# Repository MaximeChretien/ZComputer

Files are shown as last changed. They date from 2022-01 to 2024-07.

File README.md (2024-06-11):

# ZComputer

This projects aims to build a computer based on a Z80 CPU from scratch.

## Introduction

The computer is designed as a set of boards, each having a specific function.

The current planned boards are:
- Main (CPU, RAM, ROM, ...)
- Basic I/O
- Interrupt (Interrupt vector decoding and prioritizing)
- UART
- Counter/Timer
- ADC and DAC
- Storage

Those boards will then connect on the base board through a unified connector.  
The base board also includes the power input and the reset button as well as a power LED.

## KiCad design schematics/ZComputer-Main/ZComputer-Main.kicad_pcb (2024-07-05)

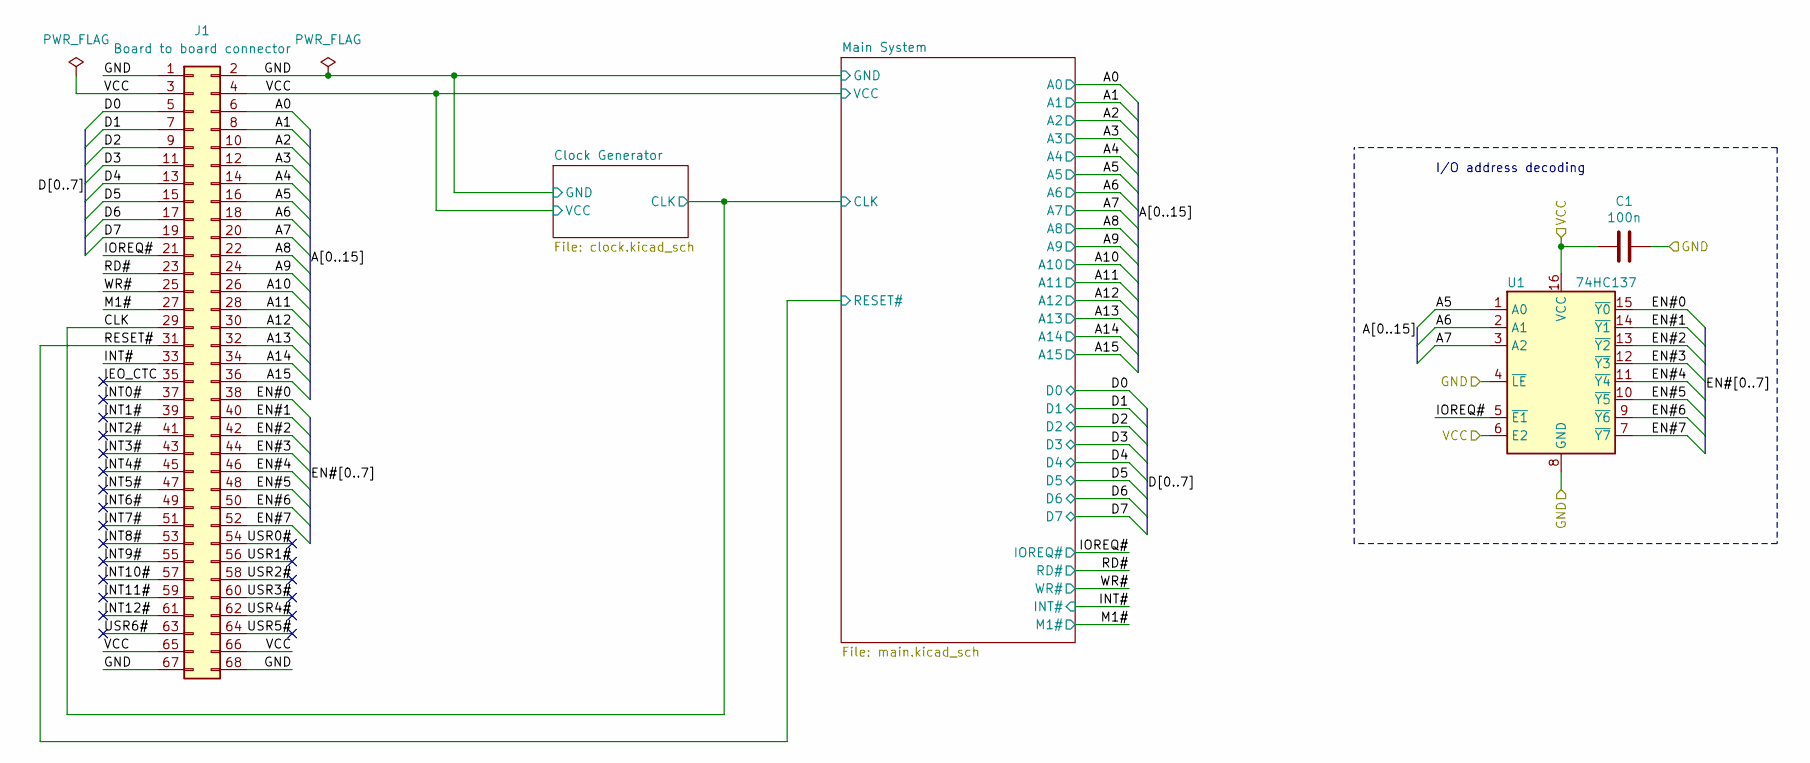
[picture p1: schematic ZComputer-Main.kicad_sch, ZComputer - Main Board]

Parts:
C1: 100n; C_Disc_D4.3mm_W1.9mm_P5.00mm
J1: Board to board connector; PinSocket_2x34_P2.54mm_Horizontal
U1: 74HC137; DIP-16_W7.62mm_Socket_LongPads

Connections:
/A0: J1.6; also elsewhere on the board
/A1: J1.8; also elsewhere on the board
/A2: J1.10; also elsewhere on the board
/A3: J1.12; also elsewhere on the board
/A4: J1.14; also elsewhere on the board
/A5: J1.16, U1.1 (A0); also elsewhere on the board
/A6: J1.18, U1.2 (A1); also elsewhere on the board
/A7: J1.20, U1.3 (A2); also elsewhere on the board
/A8: J1.22; also elsewhere on the board
/A9: J1.24; also elsewhere on the board
/A10: J1.26; also elsewhere on the board
/A11: J1.28; also elsewhere on the board
/A12: J1.30; also elsewhere on the board
/A13: J1.32; also elsewhere on the board
/A14: J1.34; also elsewhere on the board
/A15: J1.36; also elsewhere on the board
/CLK: J1.29; also elsewhere on the board
/D0: J1.5; also elsewhere on the board
/D1: J1.7; also elsewhere on the board
/D2: J1.9; also elsewhere on the board
/D3: J1.11; also elsewhere on the board
/D4: J1.13; also elsewhere on the board
/D5: J1.15; also elsewhere on the board
/D6: J1.17; also elsewhere on the board
/D7: J1.19; also elsewhere on the board
/EN#0: J1.38, U1.15 (~Y0)
/EN#1: J1.40, U1.14 (~Y1)
/EN#2: J1.42, U1.13 (~Y2)
/EN#3: J1.44, U1.12 (~Y3)
/EN#4: J1.46, U1.11 (~Y4)
/EN#5: J1.48, U1.10 (~Y5)
/EN#6: J1.50, U1.9 (~Y6)
/EN#7: J1.52, U1.7 (~Y7)
/GND: C1.1, J1.1, J1.2, J1.67, J1.68, U1.4 (~LE), U1.8 (GND); also elsewhere on the board
/IEO_CTC: J1.35
/INT0#: J1.37
/INT1#: J1.39
/INT2#: J1.41
/INT3#: J1.43
/INT4#: J1.45
/INT5#: J1.47
/INT6#: J1.49
/INT7#: J1.51
/INT8#: J1.53
/INT9#: J1.55
/INT10#: J1.57
/INT11#: J1.59
/INT12#: J1.61
/INT#: J1.33; also elsewhere on the board
/IOREQ#: J1.21, U1.5 (~E1); also elsewhere on the board
/M1#: J1.27; also elsewhere on the board
/RD#: J1.23; also elsewhere on the board
/RESET#: J1.31; also elsewhere on the board
/USR0#: J1.54
/USR1#: J1.56
/USR2#: J1.58
/USR3#: J1.60
/USR4#: J1.62
/USR5#: J1.64
/USR6#: J1.63
/VCC: C1.2, J1.3, J1.4, J1.65, J1.66, U1.6 (E2), U1.16 (VCC); also elsewhere on the board
/WR#: J1.25; also elsewhere on the board

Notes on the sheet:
I/O address decoding

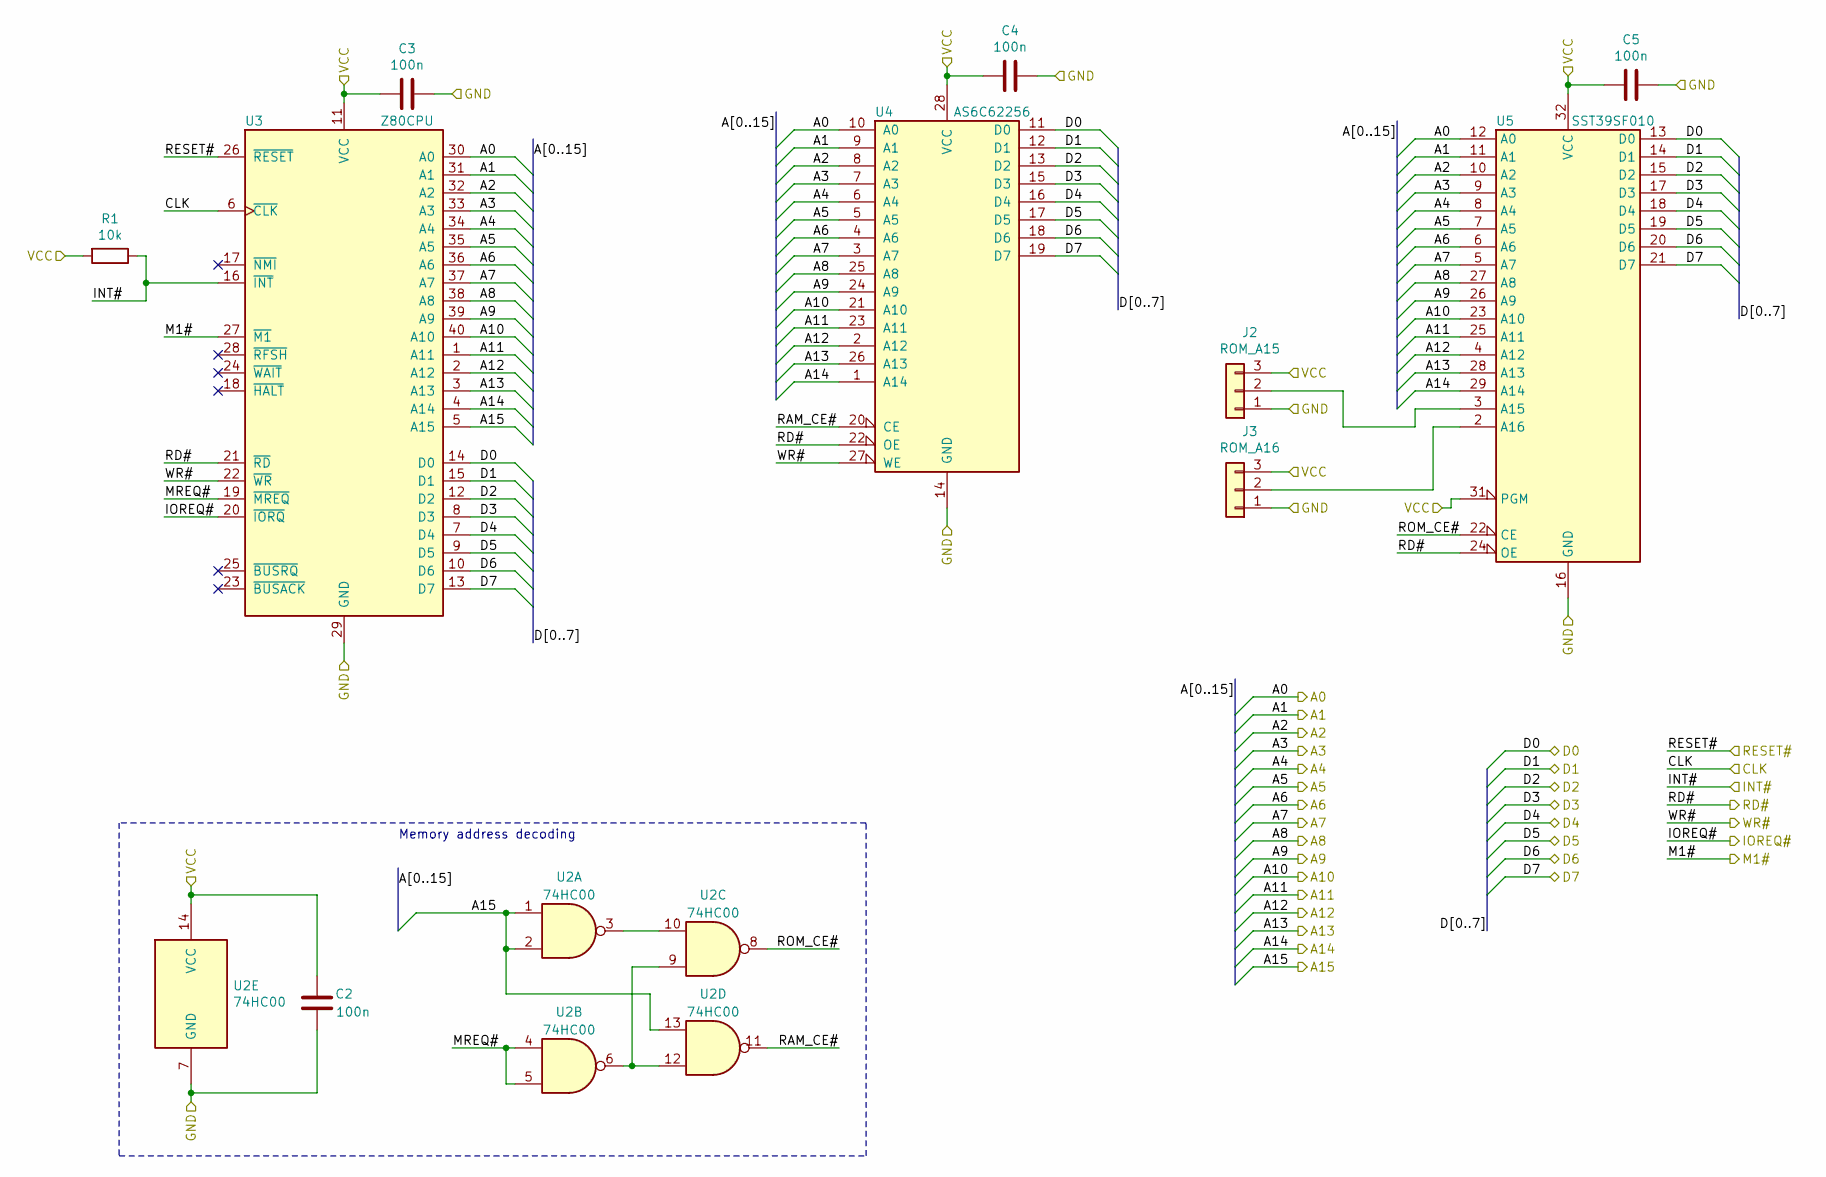
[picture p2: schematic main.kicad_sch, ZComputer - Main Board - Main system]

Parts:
C2, C3, C4, C5: 100n; C_Disc_D4.3mm_W1.9mm_P5.00mm
J2: ROM_A15; PinHeader_1x03_P2.54mm_Vertical
J3: ROM_A16; PinHeader_1x03_P2.54mm_Vertical
R1: 10k; R_Axial_DIN0207_L6.3mm_D2.5mm_P10.16mm_Horizontal
U2: 74HC00; DIP-14_W7.62mm_Socket_LongPads
U3: Z80CPU; DIP-40_W15.24mm_Socket_LongPads
U4: AS6C62256; DIP-28_W15.24mm_Socket_LongPads
U5: SST39SF010; DIP-32_W15.24mm_Socket_LongPads

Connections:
/A0: U3.30 (A0), U4.10 (A0), U5.12 (A0); also elsewhere on the board
/A1: U3.31 (A1), U4.9 (A1), U5.11 (A1); also elsewhere on the board
/A2: U3.32 (A2), U4.8 (A2), U5.10 (A2); also elsewhere on the board
/A3: U3.33 (A3), U4.7 (A3), U5.9 (A3); also elsewhere on the board
/A4: U3.34 (A4), U4.6 (A4), U5.8 (A4); also elsewhere on the board
/A5: U3.35 (A5), U4.5 (A5), U5.7 (A5); also elsewhere on the board
/A6: U3.36 (A6), U4.4 (A6), U5.6 (A6); also elsewhere on the board
/A7: U3.37 (A7), U4.3 (A7), U5.5 (A7); also elsewhere on the board
/A8: U3.38 (A8), U4.25 (A8), U5.27 (A8); also elsewhere on the board
/A9: U3.39 (A9), U4.24 (A9), U5.26 (A9); also elsewhere on the board
/A10: U3.40 (A10), U4.21 (A10), U5.23 (A10); also elsewhere on the board
/A11: U3.1 (A11), U4.23 (A11), U5.25 (A11); also elsewhere on the board
/A12: U3.2 (A12), U4.2 (A12), U5.4 (A12); also elsewhere on the board
/A13: U3.3 (A13), U4.26 (A13), U5.28 (A13); also elsewhere on the board
/A14: U3.4 (A14), U4.1 (A14), U5.29 (A14); also elsewhere on the board
/A15: U2.1, U2.2, U2.13, U3.5 (A15); also elsewhere on the board
/CLK: U3.6 (~CLK); also elsewhere on the board
/D0: U3.14 (D0), U4.11 (D0), U5.13 (D0); also elsewhere on the board
/D1: U3.15 (D1), U4.12 (D1), U5.14 (D1); also elsewhere on the board
/D2: U3.12 (D2), U4.13 (D2), U5.15 (D2); also elsewhere on the board
/D3: U3.8 (D3), U4.15 (D3), U5.17 (D3); also elsewhere on the board
/D4: U3.7 (D4), U4.16 (D4), U5.18 (D4); also elsewhere on the board
/D5: U3.9 (D5), U4.17 (D5), U5.19 (D5); also elsewhere on the board
/D6: U3.10 (D6), U4.18 (D6), U5.20 (D6); also elsewhere on the board
/D7: U3.13 (D7), U4.19 (D7), U5.21 (D7); also elsewhere on the board
/GND: C2.1, C3.1, C4.1, C5.1, J2.1, J3.1, U2.7 (GND), U3.29 (GND), U4.14 (GND), U5.16 (GND); also elsewhere on the board
/INT#: R1.1, U3.16 (~INT); also elsewhere on the board
/IOREQ#: U3.20 (~IORQ); also elsewhere on the board
/M1#: U3.27 (~M1); also elsewhere on the board
/Main System/MREQ#: U2.4, U2.5, U3.19 (~MREQ)
/Main System/RAM_CE#: U2.11, U4.20 (CE)
/Main System/ROM_CE#: U2.8, U5.22 (CE)
/RD#: U3.21 (~RD), U4.22 (OE), U5.24 (OE); also elsewhere on the board
/RESET#: U3.26 (~RESET); also elsewhere on the board
/VCC: C2.2, C3.2, C4.2, C5.2, J2.3, J3.3, R1.2, U2.14 (VCC), U3.11 (VCC), U4.28 (VCC), U5.31 (PGM), U5.32 (VCC); also elsewhere on the board
/WR#: U3.22 (~WR), U4.27 (WE); also elsewhere on the board
unnamed: J2.2, U5.3 (A15)
unnamed: J3.2, U5.2 (A16)
unnamed: U2.3, U2.10
unnamed: U2.6, U2.9, U2.12

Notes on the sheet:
Memory address decoding

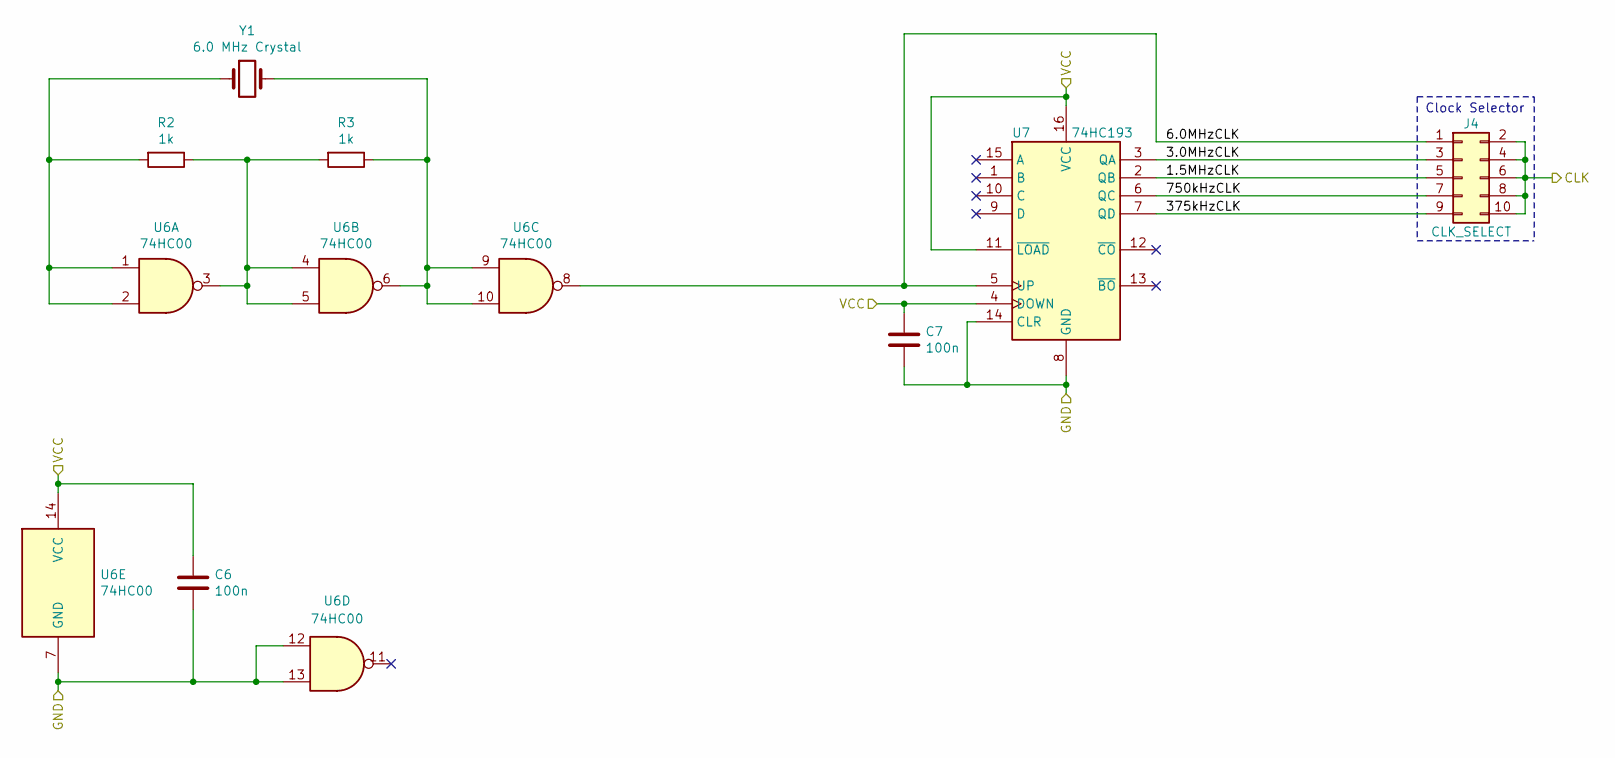
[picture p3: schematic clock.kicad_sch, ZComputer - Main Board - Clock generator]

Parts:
C6, C7: 100n; C_Disc_D4.3mm_W1.9mm_P5.00mm
J4: CLK_SELECT; PinHeader_2x05_P2.54mm_Vertical
R2, R3: 1k; R_Axial_DIN0207_L6.3mm_D2.5mm_P10.16mm_Horizontal
U6: 74HC00; DIP-14_W7.62mm_Socket_LongPads
U7: 74HC193; DIP-16_W7.62mm_Socket_LongPads
Y1: 6.0 MHz Crystal; Crystal_HC49-4H_Vertical

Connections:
/CLK: J4.2, J4.4, J4.6, J4.8, J4.10; also elsewhere on the board
/Clock Generator/1.5MHzCLK: J4.5, U7.2 (QB)
/Clock Generator/3.0MHzCLK: J4.3, U7.3 (QA)
/Clock Generator/6.0MHzCLK: J4.1, U6.8, U7.5 (UP)
/Clock Generator/375kHzCLK: J4.9, U7.7 (QD)
/Clock Generator/750kHzCLK: J4.7, U7.6 (QC)
/GND: C6.2, C7.2, U6.7 (GND), U6.12, U6.13, U7.8 (GND), U7.14 (CLR); also elsewhere on the board
/VCC: C6.1, C7.1, U6.14 (VCC), U7.4 (DOWN), U7.11 (~LOAD), U7.16 (VCC); also elsewhere on the board
unnamed: R2.1, R3.2, U6.3, U6.4, U6.5
unnamed: R2.2, U6.1, U6.2, Y1.1
unnamed: R3.1, U6.6, U6.9, U6.10, Y1.2

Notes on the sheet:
Clock Selector

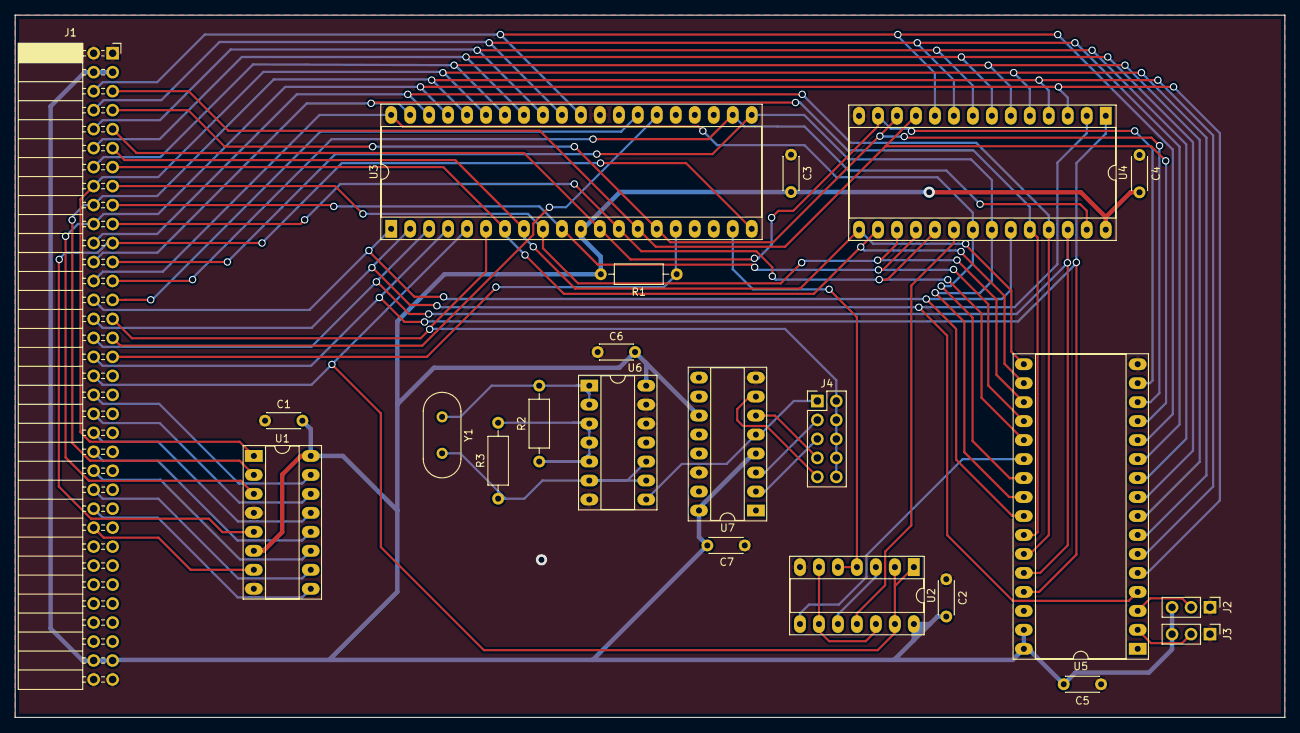
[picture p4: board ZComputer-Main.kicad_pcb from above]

Board: 2 copper layers, 169.9 x 94.0 mm, 22 parts (0 on the bottom side), 56 nets.

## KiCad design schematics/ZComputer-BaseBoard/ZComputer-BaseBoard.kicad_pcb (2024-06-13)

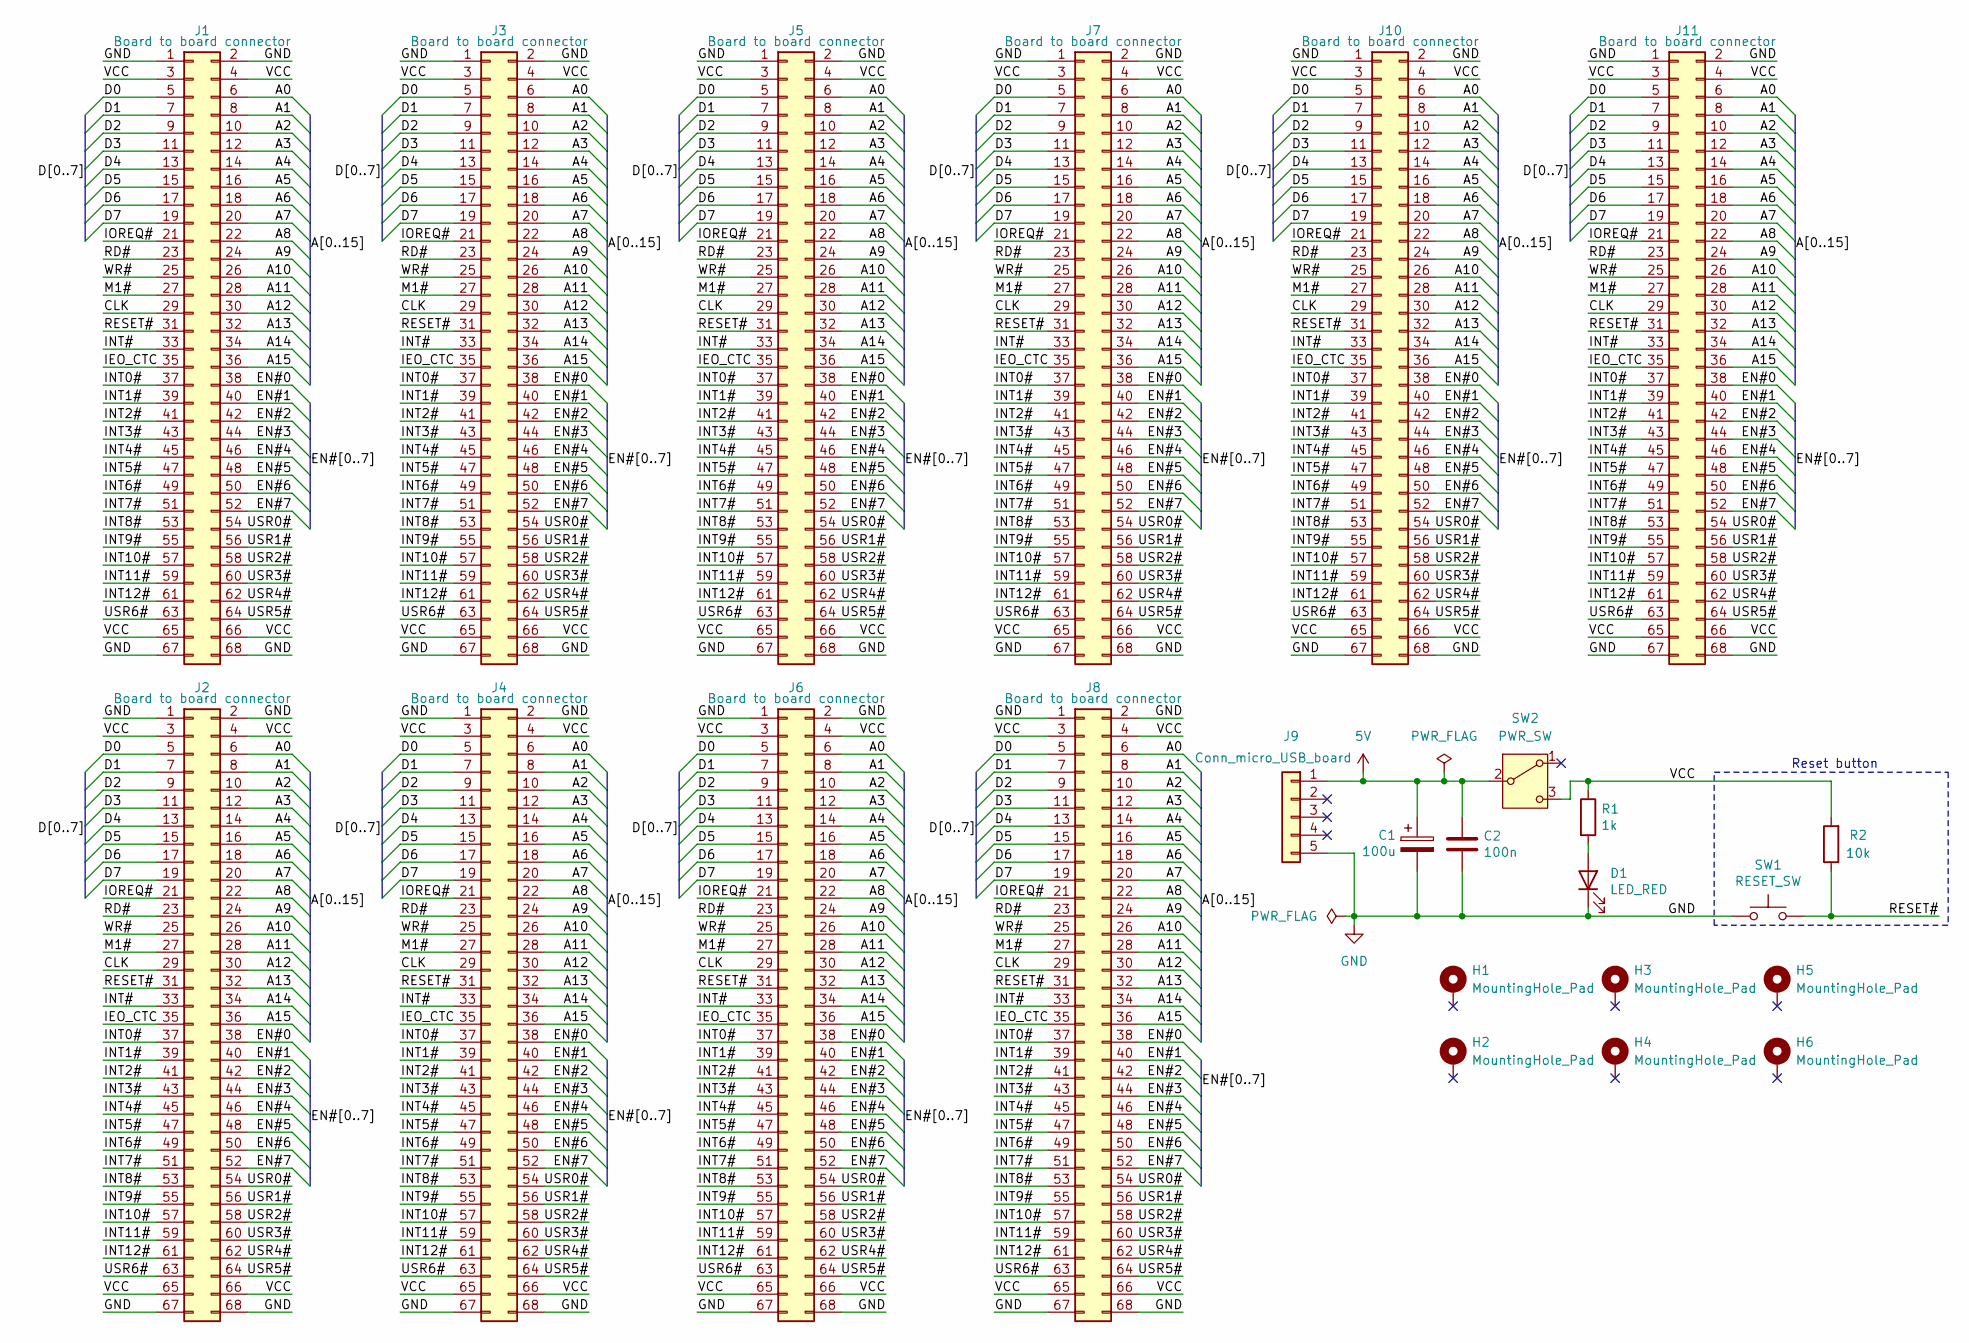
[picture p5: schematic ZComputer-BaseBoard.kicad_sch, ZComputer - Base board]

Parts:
C1: 100u; CP_Radial_D8.0mm_P2.50mm
C2: 100n; C_Disc_D4.3mm_W1.9mm_P5.00mm
D1: LED_RED; LED_D5.0mm
H1, H2, H3, H4, H5, H6: MountingHole_Pad; MountingHole_2.7mm_Pad
J1, J2, J3, J4, J5, J6, J7, J8, J10, J11: Board to board connector; PinHeader_2x34_P2.54mm_Vertical
J9: Conn_micro_USB_board; PinHeader_1x05_P2.54mm_Vertical
R1: 1k; R_Axial_DIN0207_L6.3mm_D2.5mm_P10.16mm_Horizontal
R2: 10k; R_Axial_DIN0207_L6.3mm_D2.5mm_P10.16mm_Horizontal
SW1: RESET_SW; SW_PUSH_6mm_H4.3mm
SW2: PWR_SW; SW_Slide_SPDT_Angled_CK_OS102011MA1Q

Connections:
5V: C1.1, C2.1, J9.1, SW2.2 (B)
/A0: J1.6, J2.6, J3.6, J4.6, J5.6, J6.6, J7.6, J8.6, J10.6, J11.6
/A1: J1.8, J2.8, J3.8, J4.8, J5.8, J6.8, J7.8, J8.8, J10.8, J11.8
/A2: J1.10, J2.10, J3.10, J4.10, J5.10, J6.10, J7.10, J8.10, J10.10, J11.10
/A3: J1.12, J2.12, J3.12, J4.12, J5.12, J6.12, J7.12, J8.12, J10.12, J11.12
/A4: J1.14, J2.14, J3.14, J4.14, J5.14, J6.14, J7.14, J8.14, J10.14, J11.14
/A5: J1.16, J2.16, J3.16, J4.16, J5.16, J6.16, J7.16, J8.16, J10.16, J11.16
/A6: J1.18, J2.18, J3.18, J4.18, J5.18, J6.18, J7.18, J8.18, J10.18, J11.18
/A7: J1.20, J2.20, J3.20, J4.20, J5.20, J6.20, J7.20, J8.20, J10.20, J11.20
/A8: J1.22, J2.22, J3.22, J4.22, J5.22, J6.22, J7.22, J8.22, J10.22, J11.22
/A9: J1.24, J2.24, J3.24, J4.24, J5.24, J6.24, J7.24, J8.24, J10.24, J11.24
/A10: J1.26, J2.26, J3.26, J4.26, J5.26, J6.26, J7.26, J8.26, J10.26, J11.26
/A11: J1.28, J2.28, J3.28, J4.28, J5.28, J6.28, J7.28, J8.28, J10.28, J11.28
/A12: J1.30, J2.30, J3.30, J4.30, J5.30, J6.30, J7.30, J8.30, J10.30, J11.30
/A13: J1.32, J2.32, J3.32, J4.32, J5.32, J6.32, J7.32, J8.32, J10.32, J11.32
/A14: J1.34, J2.34, J3.34, J4.34, J5.34, J6.34, J7.34, J8.34, J10.34, J11.34
/A15: J1.36, J2.36, J3.36, J4.36, J5.36, J6.36, J7.36, J8.36, J10.36, J11.36
/CLK: J1.29, J2.29, J3.29, J4.29, J5.29, J6.29, J7.29, J8.29, J10.29, J11.29
/D0: J1.5, J2.5, J3.5, J4.5, J5.5, J6.5, J7.5, J8.5, J10.5, J11.5
/D1: J1.7, J2.7, J3.7, J4.7, J5.7, J6.7, J7.7, J8.7, J10.7, J11.7
/D2: J1.9, J2.9, J3.9, J4.9, J5.9, J6.9, J7.9, J8.9, J10.9, J11.9
/D3: J1.11, J2.11, J3.11, J4.11, J5.11, J6.11, J7.11, J8.11, J10.11, J11.11
/D4: J1.13, J2.13, J3.13, J4.13, J5.13, J6.13, J7.13, J8.13, J10.13, J11.13
/D5: J1.15, J2.15, J3.15, J4.15, J5.15, J6.15, J7.15, J8.15, J10.15, J11.15
/D6: J1.17, J2.17, J3.17, J4.17, J5.17, J6.17, J7.17, J8.17, J10.17, J11.17
/D7: J1.19, J2.19, J3.19, J4.19, J5.19, J6.19, J7.19, J8.19, J10.19, J11.19
/EN#0: J1.38, J2.38, J3.38, J4.38, J5.38, J6.38, J7.38, J8.38, J10.38, J11.38
/EN#1: J1.40, J2.40, J3.40, J4.40, J5.40, J6.40, J7.40, J8.40, J10.40, J11.40
/EN#2: J1.42, J2.42, J3.42, J4.42, J5.42, J6.42, J7.42, J8.42, J10.42, J11.42
/EN#3: J1.44, J2.44, J3.44, J4.44, J5.44, J6.44, J7.44, J8.44, J10.44, J11.44
/EN#4: J1.46, J2.46, J3.46, J4.46, J5.46, J6.46, J7.46, J8.46, J10.46, J11.46
/EN#5: J1.48, J2.48, J3.48, J4.48, J5.48, J6.48, J7.48, J8.48, J10.48, J11.48
/EN#6: J1.50, J2.50, J3.50, J4.50, J5.50, J6.50, J7.50, J8.50, J10.50, J11.50
/EN#7: J1.52, J2.52, J3.52, J4.52, J5.52, J6.52, J7.52, J8.52, J10.52, J11.52
/IEO_CTC: J1.35, J2.35, J3.35, J4.35, J5.35, J6.35, J7.35, J8.35, J10.35, J11.35
/INT0#: J1.37, J2.37, J3.37, J4.37, J5.37, J6.37, J7.37, J8.37, J10.37, J11.37
/INT1#: J1.39, J2.39, J3.39, J4.39, J5.39, J6.39, J7.39, J8.39, J10.39, J11.39
/INT2#: J1.41, J2.41, J3.41, J4.41, J5.41, J6.41, J7.41, J8.41, J10.41, J11.41
/INT3#: J1.43, J2.43, J3.43, J4.43, J5.43, J6.43, J7.43, J8.43, J10.43, J11.43
/INT4#: J1.45, J2.45, J3.45, J4.45, J5.45, J6.45, J7.45, J8.45, J10.45, J11.45
/INT5#: J1.47, J2.47, J3.47, J4.47, J5.47, J6.47, J7.47, J8.47, J10.47, J11.47
/INT6#: J1.49, J2.49, J3.49, J4.49, J5.49, J6.49, J7.49, J8.49, J10.49, J11.49
/INT7#: J1.51, J2.51, J3.51, J4.51, J5.51, J6.51, J7.51, J8.51, J10.51, J11.51
/INT8#: J1.53, J2.53, J3.53, J4.53, J5.53, J6.53, J7.53, J8.53, J10.53, J11.53
/INT9#: J1.55, J2.55, J3.55, J4.55, J5.55, J6.55, J7.55, J8.55, J10.55, J11.55
/INT10#: J1.57, J2.57, J3.57, J4.57, J5.57, J6.57, J7.57, J8.57, J10.57, J11.57
/INT11#: J1.59, J2.59, J3.59, J4.59, J5.59, J6.59, J7.59, J8.59, J10.59, J11.59
/INT12#: J1.61, J2.61, J3.61, J4.61, J5.61, J6.61, J7.61, J8.61, J10.61, J11.61
/INT#: J1.33, J2.33, J3.33, J4.33, J5.33, J6.33, J7.33, J8.33, J10.33, J11.33
/IOREQ#: J1.21, J2.21, J3.21, J4.21, J5.21, J6.21, J7.21, J8.21, J10.21, J11.21
/M1#: J1.27, J2.27, J3.27, J4.27, J5.27, J6.27, J7.27, J8.27, J10.27, J11.27
/RD#: J1.23, J2.23, J3.23, J4.23, J5.23, J6.23, J7.23, J8.23, J10.23, J11.23
/RESET#: J1.31, J2.31, J3.31, J4.31, J5.31, J6.31, J7.31, J8.31, J10.31, J11.31, R2.1, SW1.2
/USR0#: J1.54, J2.54, J3.54, J4.54, J5.54, J6.54, J7.54, J8.54, J10.54, J11.54
/USR1#: J1.56, J2.56, J3.56, J4.56, J5.56, J6.56, J7.56, J8.56, J10.56, J11.56
/USR2#: J1.58, J2.58, J3.58, J4.58, J5.58, J6.58, J7.58, J8.58, J10.58, J11.58
/USR3#: J1.60, J2.60, J3.60, J4.60, J5.60, J6.60, J7.60, J8.60, J10.60, J11.60
/USR4#: J1.62, J2.62, J3.62, J4.62, J5.62, J6.62, J7.62, J8.62, J10.62, J11.62
/USR5#: J1.64, J2.64, J3.64, J4.64, J5.64, J6.64, J7.64, J8.64, J10.64, J11.64
/USR6#: J1.63, J2.63, J3.63, J4.63, J5.63, J6.63, J7.63, J8.63, J10.63, J11.63
/VCC: J1.3, J1.4, J1.65, J1.66, J2.3, J2.4, J2.65, J2.66, J3.3, J3.4, J3.65, J3.66, J4.3, J4.4, J4.65, J4.66, J5.3, J5.4, J5.65, J5.66, J6.3, J6.4, J6.65, J6.66, J7.3, J7.4, J7.65, J7.66, J8.3, J8.4, J8.65, J8.66, J10.3, J10.4, J10.65, J10.66, J11.3, J11.4, J11.65, J11.66, R1.1, R2.2, SW2.3 (C)
/WR#: J1.25, J2.25, J3.25, J4.25, J5.25, J6.25, J7.25, J8.25, J10.25, J11.25
GND: C1.2, C2.2, D1.1 (K), J1.1, J1.2, J1.67, J1.68, J2.1, J2.2, J2.67, J2.68, J3.1, J3.2, J3.67, J3.68, J4.1, J4.2, J4.67, J4.68, J5.1, J5.2, J5.67, J5.68, J6.1, J6.2, J6.67, J6.68, J7.1, J7.2, J7.67, J7.68, J8.1, J8.2, J8.67, J8.68, J9.5, J10.1, J10.2, J10.67, J10.68, J11.1, J11.2, J11.67, J11.68, SW1.1
unnamed: D1.2 (A), R1.2

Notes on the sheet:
Reset button

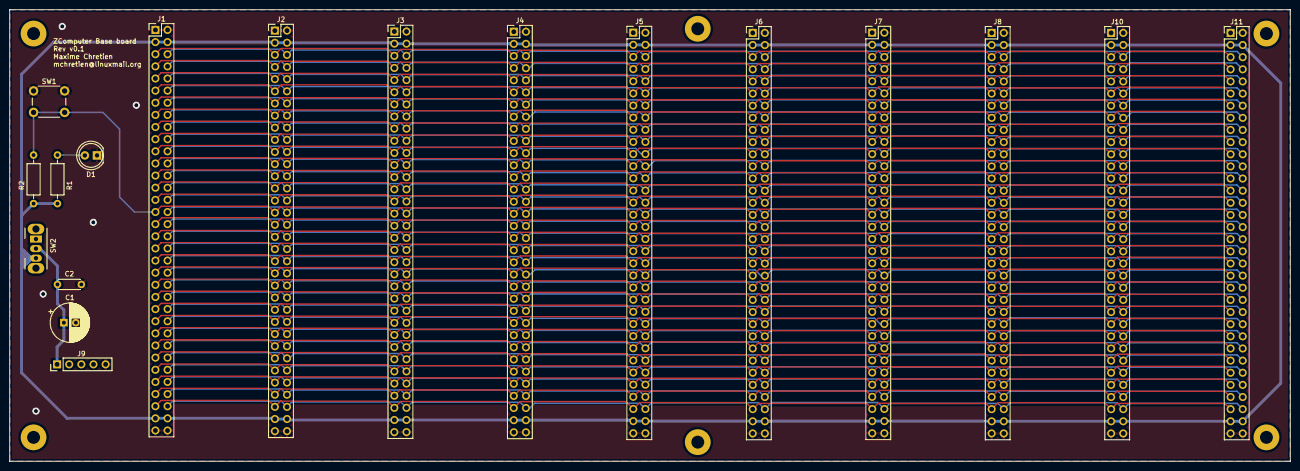
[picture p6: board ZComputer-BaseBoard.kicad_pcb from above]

Board: 2 copper layers, 268.0 x 94.5 mm, 24 parts (0 on the bottom side), 64 nets.

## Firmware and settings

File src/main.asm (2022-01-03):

include "zcomputer.asm"

DATA1:	EQU 0x1000
DATA2:	EQU 0x2000
DATA3:	EQU 0x3521
DATA4:	EQU 0x5926

	LD SP, STACK

	; Init all memory locations
	LD A, 0
	LD HL, DATA1
	LD (HL), A
	LD HL, DATA2
	LD (HL), A
	LD HL, DATA3
	LD (HL), A
	LD HL, DATA4
	LD (HL), A
START:
	; Output all ports values
	LD HL, DATA1
	LD A, (HL)
	OUT (PORTD_OUT), A

	LD HL, DATA2
	LD A, (HL)
	OUT (PORTC_OUT), A

	LD HL, DATA3
	LD A, (HL)
	OUT (PORTB_OUT), A

	LD HL, DATA4
	LD A, (HL)
	OUT (PORTA_OUT), A

	; INC 32 bits counter
	; then tempo
	LD HL, DATA1
	INC (HL)
	JP NZ, START_TEMPO

	LD HL, DATA2
	INC (HL)
	JP NZ, START_TEMPO

	LD HL, DATA3
	INC (HL)
	JP NZ, START_TEMPO

	JP NZ, DATA4
	INC (HL)

START_TEMPO:
	LD A, 0
	LD C, 0
TEMPO:
	INC A
	JP NZ, TEMPO
TEMPO2:
	INC C
	JP NZ,TEMPO
	JP START

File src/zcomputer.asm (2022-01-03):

; RAM Addresses
STACK: EQU 0x8000

; I/O PORTs Addresses
PORTA_OUT: EQU 0x00
PORTA_IN: EQU 0x04
PORTB_OUT: EQU 0x08
PORTB_IN: EQU 0x0C
PORTC_OUT: EQU 0x10
PORTC_IN: EQU 0x14
PORTD_OUT: EQU 0x18
PORTD_IN: EQU 0x1C

; I/O CTC Adresses
CTC_CHANNEL0: EQU 0x20
CTC_CHANNEL1: EQU 0x28
CTC_CHANNEL2: EQU 0x30
CTC_CHANNEL3: EQU 0x38

; I/O UART Adresses
UART0_RECEIVE_BUFFER: EQU 0x40
UART0_TRANSMIT_REG: EQU 0x40
UART0_DIV_LATCH_LSB: EQU 0x40
UART0_INT_EN: EQU 0x42
UART0_DIV_LATCH_MSB: EQU 0x42
UART0_INT_ID: EQU 0x44
UART0_FIFO_CTRL: EQU 0x44
UART0_LINE_CTRL: EQU 0x46
UART0_MODEM_CTRL: EQU 0x48
UART0_LINE_STATUS: EQU 0x4A
UART0_MODEM_STATUS: EQU 0x4C
UART0_SCRATCH: EQU 0x4E

UART1_RECEIVE_BUFFER: EQU 0x50
UART1_TRANSMIT_REG: EQU 0x50
UART1_DIV_LATCH_LSB: EQU 0x50
UART1_INT_EN: EQU 0x52
UART1_DIV_LATCH_MSB: EQU 0x52
UART1_INT_ID: EQU 0x54
UART1_FIFO_CTRL: EQU 0x54
UART1_LINE_CTRL: EQU 0x56
UART1_MODEM_CTRL: EQU 0x58
UART1_LINE_STATUS: EQU 0x5A
UART1_MODEM_STATUS: EQU 0x5C
UART1_SCRATCH: EQU 0x5E

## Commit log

2022-10-11 Migrate to KiCad 6
    [ZComputer.kicad_pcb, ZComputer.kicad_sch, ZComputer.sch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]
2024-06-10 Move old schematics to a new folder
    [ZComputer.kicad_pcb, ZComputer.kicad_sch, ZComputerClock.kicad_sch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]
2024-06-10 Add new Main board schematics
    This is done with KiCAD 8.0 now.
    [ZComputer-Main.kicad_pcb, ZComputer-Main.kicad_sch, clock.kicad_sch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]
2024-06-11 Add base board schematic and PCB design
    [ZComputer-BaseBoard.kicad_pcb, ZComputer-BaseBoard.kicad_sch]
2024-06-13 Add power switch on the base board
    [ZComputer-BaseBoard.kicad_pcb, ZComputer-BaseBoard.kicad_sch]
2024-06-21 Add I/O ports board schematics
    [ZComputer-IO.kicad_pcb, ZComputer-IO.kicad_sch, input.kicad_sch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]
2024-07-05 Main board: Add PCB layout
    [ZComputer-Main.kicad_pcb, ZComputer-Main.kicad_sch, clock.kicad_sch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]
